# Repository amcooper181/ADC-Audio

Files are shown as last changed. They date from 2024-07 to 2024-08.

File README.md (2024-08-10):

# ESP32 Analog to Digital Streamer

## Overview

The **ESP32 Analog to Digital Streamer** is a project designed to capture analog audio signals and stream them using the ESP32 microcontroller. The PCM1862 ADC this project is based on is feature-rich, highly customizable, and offers a 100dB+ signal to noise ratio.

## Features

- **High-Quality Audio Capture:** Utilizes the PCM1862 ADC for precise analog-to-digital conversion.
- **Real-Time Streaming:** Stream audio data over Wi-Fi using the ESP32's built-in capabilities.
- **High Sample Rate:** 96 kHz at 24 bits
- **Low Latency:** Optimized for low-latency streaming to ensure real-time audio processing.
- **Input Options:** This device allows for inputs via a 3.5mm TRRS connector or RCA cables
- **Input Levels:** Supports line-level inputs. The PCM1862 has a configurable, 2 level gain amplifier that can be used for phono inputs, but for the best quality a dedicated, external amplifier is recommended.

## Getting Started

### Hardware

- **Prototype Stage** The KiCad files are available for the first prototype, located in [adcesp32_kicad/](./adcesp32_kicad//)
- **Power Supply** The device requires a USB-C power supply.

### Software

- **Building the Project** All files needed to build the project in PlatformIO are included in this repo
- **Basic Functionality** As of now, the software included in this repo will allow the user to convert an analog input to digital output. An I2S amplifier can be can be connected to listen to playback.
- **Buffered Data** The data is buffered before being sent to the DOUT pin on the PCM1862. This was done to prototype data processing speed.
- **Work In Progress** The software will be updated, improved, and finalized upon finalization of the hardware. The hardware is currently on order, and 5 demo boards should arrive by 9/1/2024

### License
This project is licensed under the GPL V3 License. See the [LICENSE](./LICENSE) file for details.

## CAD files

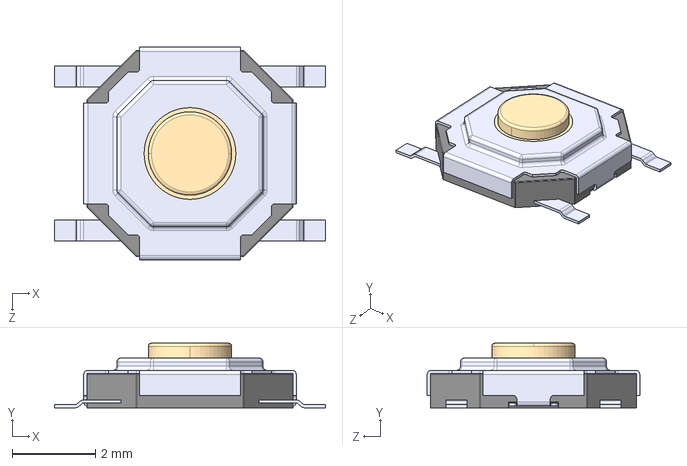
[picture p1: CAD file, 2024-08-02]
adcesp32_kicad/KiCad/TS-1187A-B-A-B.step
6.50 x 1.55 x 5.10 mm

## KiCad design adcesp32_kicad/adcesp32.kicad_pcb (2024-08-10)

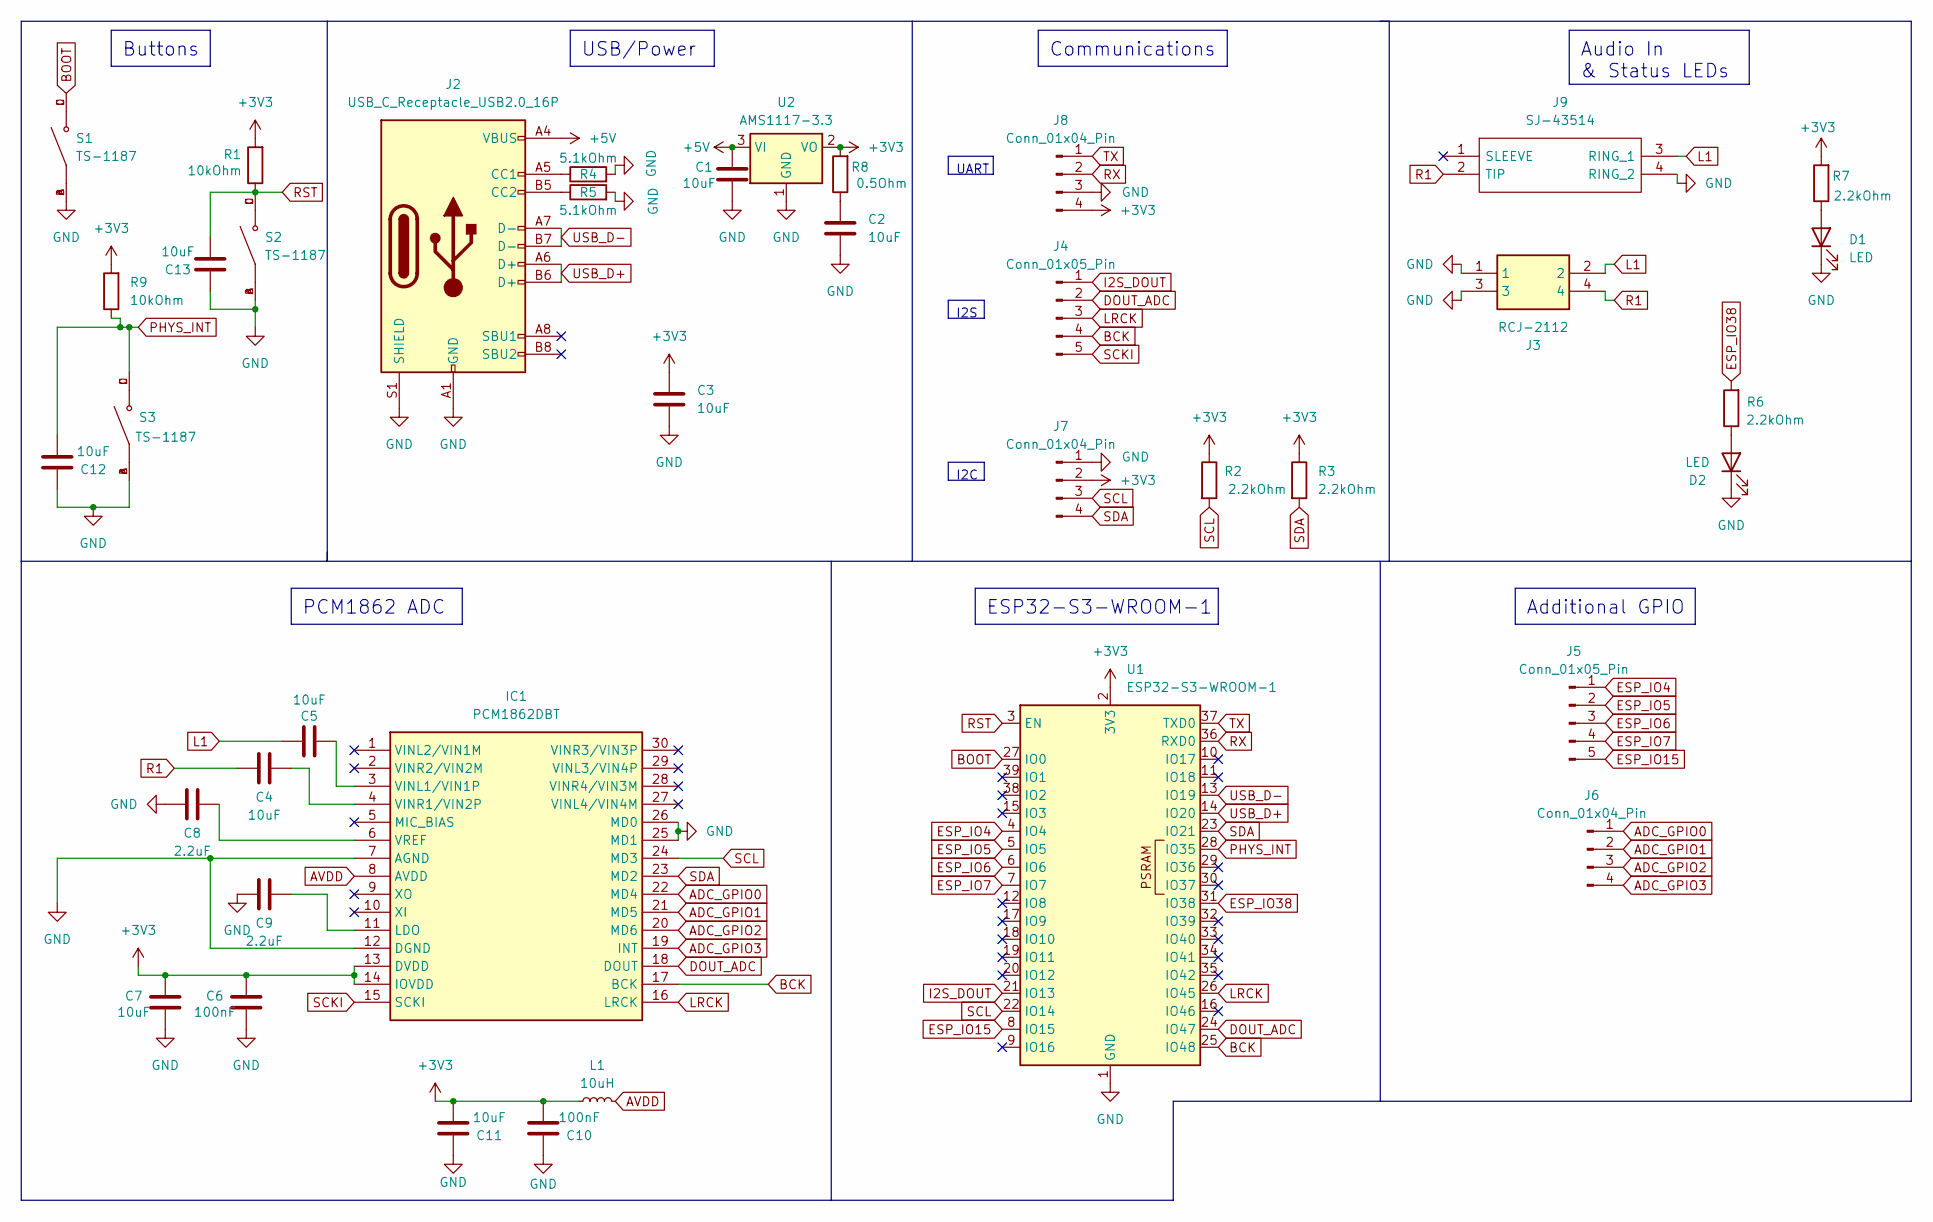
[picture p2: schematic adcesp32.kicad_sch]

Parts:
C1, C2, C3, C4, C5, C7, C11, C12, C13: 10uF; C_0402_1005Metric
C6, C10: 100nF; C_0402_1005Metric
C8, C9: 2.2uF; C_0402_1005Metric
D1, D2: LED; R_0805_2012Metric
IC1: PCM1862DBT; SOP50P640X120-30N; Mouser Part Number 595-PCM1862DBT
J2: USB_C_Receptacle_USB2.0_16P; USB_C_Receptacle_HRO_TYPE-C-31-M-12
J3: RCJ-2112; RCJ2112; Mouser Part Number 490-RCJ-2112
J4, J5: Conn_01x05_Pin; PinHeader_1x05_P2.54mm_Vertical
J6, J7, J8: Conn_01x04_Pin; PinHeader_1x04_P2.54mm_Vertical
J9: SJ-43514; SJ43514; Mouser Part Number 490-SJ-43514
L1: 10uH; L_0805_2012Metric
R1, R9: 10kOhm; R_0402_1005Metric
R2, R3, R6, R7: 2.2kOhm; R_0603_1608Metric
R4, R5: 5.1kOhm; R_0402_1005Metric
R8: 0.5Ohm; R_0603_1608Metric
S1, S2, S3: TS-1187; SW_TS-1187A-B-A-B; PARTREV A0
U1: ESP32-S3-WROOM-1
U2: AMS1117-3.3; SOT-223-3_TabPin2

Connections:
+3V3: C3.1, C6.2, C7.2, C10.2, C11.2, IC1.13 (DVDD), IC1.14 (IOVDD), J7.2, J8.4, L1.1, R1.2, R2.1, R3.1, R7.2, R8.2, R9.2, U1.2 (3V3), U2.2 (VO)
+5V: C1.1, J2.A4 (VBUS), J2.A9 (VBUS), J2.B4 (VBUS), J2.B9 (VBUS), U2.3 (VI)
ADC_GPIO0: IC1.22 (MD4), J6.1
ADC_GPIO1: IC1.21 (MD5), J6.2
ADC_GPIO2: IC1.20 (MD6), J6.3
ADC_GPIO3: IC1.19 (INT), J6.4
AVDD: IC1.8 (AVDD), L1.2
BCK: IC1.17 (BCK), J4.4, U1.25 (IO48)
BOOT: S1.C, S1.D, U1.27 (IO0)
DOUT_ADC: IC1.18 (DOUT), J4.2, U1.24 (IO47)
ESP_IO4: J5.1, U1.4 (IO4)
ESP_IO5: J5.2, U1.5 (IO5)
ESP_IO6: J5.3, U1.6 (IO6)
ESP_IO7: J5.4, U1.7 (IO7)
ESP_IO15: J5.5, U1.8 (IO15)
ESP_IO38: R6.2, U1.31 (IO38)
GND: C1.2, C2.2, C3.2, C6.1, C7.1, C8.1, C9.1, C10.1, C11.1, C12.1, C13.1, D1.1 (K), D2.1 (K), IC1.7 (AGND), IC1.12 (DGND), IC1.25 (MD1), IC1.26 (MD0), J2.A1 (GND), J2.A12 (GND), J2.B1 (GND), J2.B12 (GND), J2.S1 (SHIELD), J3.1, J3.3, J7.1, J8.3, J9.4 (RING_2), R4.2, R5.2, S1.A, S1.B, S2.A, S2.B, S3.A, S3.B, U1.1 (GND), U1.40 (GND), U1.41 (GND), U2.1 (GND)
I2S_DOUT: J4.1, U1.21 (IO13)
L1: C5.1, J3.2, J9.3 (RING_1)
LRCK: IC1.16 (LRCK), J4.3, U1.26 (IO45)
unnamed: C2.1, R8.1
unnamed: D1.2 (A), R7.1
unnamed: D2.2 (A), R6.1
unnamed: C9.2, IC1.11 (LDO)
unnamed: C5.2, IC1.3 (VINL1/VIN1P)
unnamed: C4.2, IC1.4 (VINR1/VIN2P)
unnamed: C8.2, IC1.6 (VREF)
unnamed: J2.A5 (CC1), R4.1
unnamed: J2.B5 (CC2), R5.1
PHYS_INT: C12.2, R9.1, S3.C, S3.D, U1.28 (IO35)
R1: C4.1, J3.4, J9.2 (TIP)
RST: C13.2, R1.1, S2.C, S2.D, U1.3 (EN)
RX: J8.2, U1.36 (RXD0)
SCKI: IC1.15 (SCKI), J4.5
SCL: IC1.24 (MD3), J7.3, R2.2, U1.22 (IO14)
SDA: IC1.23 (MD2), J7.4, R3.2, U1.23 (IO21)
TX: J8.1, U1.37 (TXD0)
USB_D+: J2.A6 (D+), J2.B6 (D+), U1.14 (IO20)
USB_D-: J2.A7 (D-), J2.B7 (D-), U1.13 (IO19)

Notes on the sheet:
Buttons
UART
Additional GPIO
I2C
I2S
PCM1862 ADC
Communications
Audio In & Status LEDs
ESP32-S3-WROOM-1
USB/Power

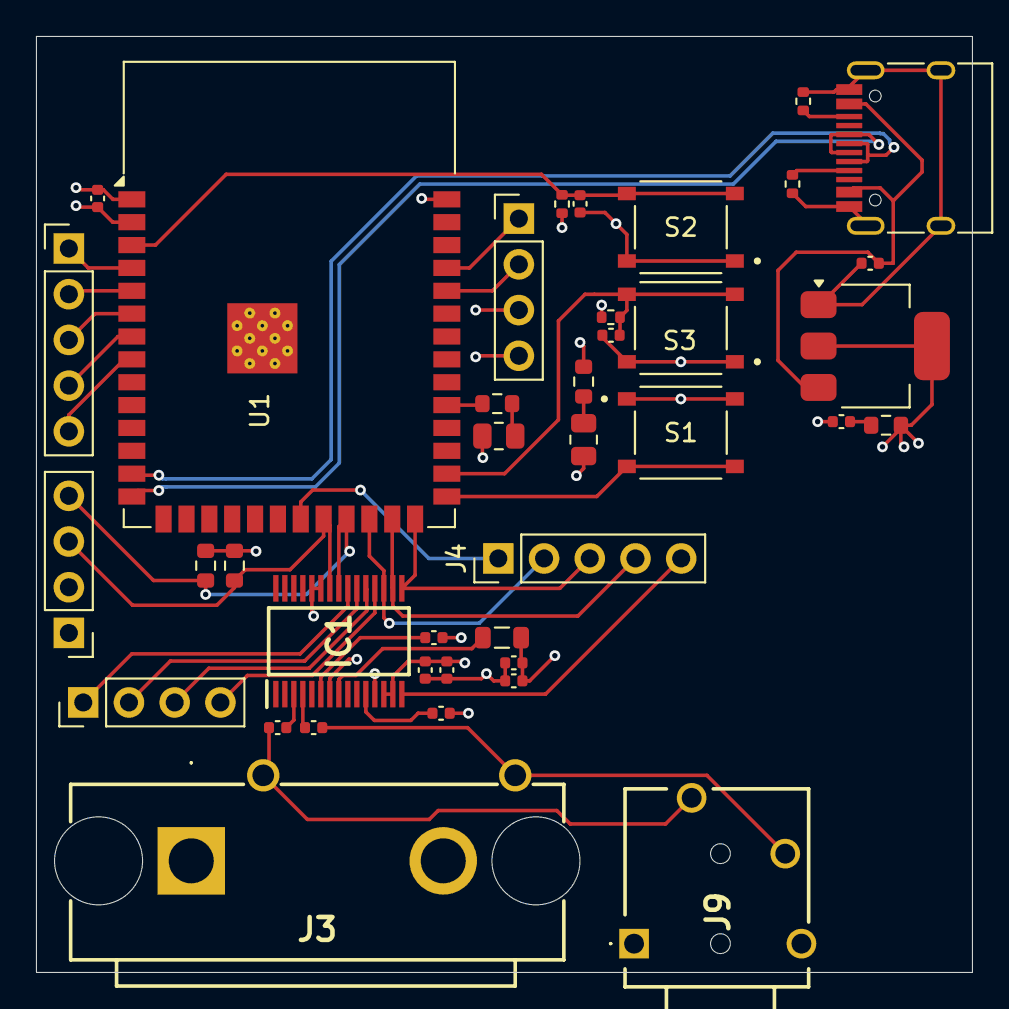
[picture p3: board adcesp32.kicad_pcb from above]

Board: 4 copper layers, 52.0 x 52.0 mm, 39 parts (0 on the bottom side), 39 nets.

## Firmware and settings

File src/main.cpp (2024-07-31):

#include <pcm1862.h>
#include <Arduino.h>
#include <ESP_I2S.h>

// Define the I2C address of the PCM1862
#define PCM1862_I2C_ADDRESS 0x4A

void i2cInitialize();

PCM1862 pcm(PCM1862_I2C_ADDRESS);
I2SClass I2S;


void setup() {
  // Initialize serial communication for debugging
  Serial.begin(115200);

  Serial.println("Starting I2C communication...");
  i2cInitialize();
  pcm.verifyConnection();
  int8_t bck = 14;
  int8_t ws = 25;
  int8_t dout = 13;
  int8_t din = 26;
  I2S.setPins(bck, ws, dout, din);
  int start = I2S.begin(I2S_MODE_STD, 96000, I2S_DATA_BIT_WIDTH_32BIT, I2S_SLOT_MODE_STEREO);
}
const int buff_size = 4096;
char buffer[buff_size];
int available_bytes, read_bytes;


void loop() {

  I2S.read();
  available_bytes = I2S.available();

  read_bytes = I2S.readBytes(buffer, available_bytes < buff_size ? available_bytes : buff_size);

  for (int i = 0; i < read_bytes; i += sizeof(buffer)) {
    I2S.write((uint8_t *) &buffer[i], std::min(buff_size, read_bytes - i));
  }
}

/// @brief Initialize i2c communication on the ESP32
void i2cInitialize() {
    // Initialize I2C communication
    Wire.begin();
    Wire.setClock(400000); // Set I2C frequency to 400kHz (fast mode)

    // Delay to allow the system to stabilize
    delay(1000);
}

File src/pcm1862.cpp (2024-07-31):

#include <pcm1862.h>

/// @brief Main Class Initializer for the PCM1862 object.
/// @param i2c_address The i2c address of the PCM1862, in slave mode (0x4A, 0x4B) determined by pin 25 LOW or HIGH
PCM1862::PCM1862(uint8_t i2cAddress) : _i2cAddress(i2cAddress) {}

void PCM1862::verifyConnection() {
    Wire.beginTransmission(_i2cAddress);
    uint8_t error = Wire.endTransmission();
    if (!error) {
        Serial.println("PCM1862 found.");
    }
    else {
        Serial.print("Could not conect to PCM1862 due to error: ");
        Serial.println(error);
    }
}

void PCM1862::_selectRegister(uint8_t registerAddress) {

    Wire.beginTransmission(_i2cAddress);
    Wire.write(0x78);
    Wire.endTransmission(false);  // Set false to keep control of the bus, because there will always be a read/write after.
}

void PCM1862::readRegister(uint8_t registerAddress) {
    _selectRegister(registerAddress);
    Wire.requestFrom(_i2cAddress, 1);  // 1 Byte registers  
    if (Wire.available()) {  // Don't block if there isn'y aynthing to read.
        byte readByte = Wire.read();
        Serial.print("Read Byte: ");
        Serial.println(readByte, HEX);
    }
    else {
        Serial.println("Failed to read data from PCM1862");
    }
}

// void PCM1862::writeRegister(uint8_t registerAddress, uint8_t value) {
//     _selectRegister(registerAddress);
//     Wire.beginTransmission(_i2cAddress);  // 1 Byte registers  
//     Wire.write(val);
//     Wire.endTransmission();
// }

// void PCM1862::setAutoGain(bool setting) {
//     _selectRegister(0x05)

// }

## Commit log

2024-07-31 added kicad files
    [adcesp32.kicad_pcb, adcesp32.kicad_sch]
2024-08-01 updated schematic
    [adcesp32.kicad_sch]
2024-08-01 added cap values
    [adcesp32.kicad_sch]
2024-08-02 completed pcb design
    [TS-1187A-B-A-B.step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]
2024-08-10 completed 52x52 pcb design
    [adcesp32-B_Cu.gbl, adcesp32-B_Mask.gbs, adcesp32-B_Paste.gbp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]
2024-08-10 removed grbr/drl
    [adcesp32-B_Cu.gbl, adcesp32-B_Mask.gbs, adcesp32-B_Paste.gbp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]
